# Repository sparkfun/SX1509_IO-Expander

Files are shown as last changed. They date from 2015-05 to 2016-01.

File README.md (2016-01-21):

SparkFun 16 Output I/O Expander Breakout - SX1509
======================================

[SX1509 16 Output I/O Expander Breakout  
*SX1509 16 Output I/O Expander Breakout (BOB-13601)*](https://www.sparkfun.com/products/13601)

The SX1509 16 Output I/O Expander Breakout Board makes it easy to prototype using the SX1509 so you can add more I/O onto your Arduino or I/O limited controller. It can leverage your I2C interface for 16 extra channels of GPIO and contains a fully programmable LED driver and a keypad scanning engine which enables continuous keypad monitoring of up to 64 keys. Since the I/O banks can operate between 1.2V and 3.6V (5.5V tolerant) independent of both the core and each other, this device can also work as a level-shifter.

Features include:

* 16 channels of bi-directional I/O - Pull-up/down resistors, push/pull or open-drain outputs, programmable polarity.
* 5.5V tolerant I/O's (1.2-3.6V operating voltage)
* LED Driver: PWM and blink control on all I/O's, breathe capability on a select few.
* Level shifting I/O's: Independent I/O rails (VCC1, VCC2) allow for up/down level shifting.
* Keypad scanning engine: Supports up to 64 keys (in an 8x8 matrix configuration).

Repository Contents
-------------------
* **/Hardware** - Eagle design files (.brd, .sch)
* **/Libraries** - Libraries for use with the <PRODUCT NAME>
* **/Production** - Production panel files (.brd)

Documentation
--------------
* **[Library](https://github.com/sparkfun/SparkFun_SX1509_Arduino_Library)** - <LANGUAGE> library for the SX1509.
* **[Hookup Guide](https://learn.sparkfun.com/tutorials/sx1509-io-expander-breakout-hookup-guide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)** - Basic hookup guide for the SX1509.
* **[SparkFun Fritzing repo](https://github.com/sparkfun/Fritzing_Parts)** - Fritzing diagrams for SparkFun products.
* **[SparkFun 3D Model repo](https://github.com/sparkfun/3D_Models)** - 3D models of SparkFun products. 
* **[SparkFun Graphical Datasheets](https://github.com/sparkfun/Graphical_Datasheets)** -Graphical Datasheets for various SparkFun products.

Product Versions
-------------------

* [BOB-13601](https://www.sparkfun.com/products/13601) - SX1509 16 I/O Breakout Board (v20)
* [BOB-11502](https://www.sparkfun.com/products/retired/11502)- (Retired) SX1509 16 I/O I2C port expander (v10)

License Information
-------------------
This product is _**open source**_! 

The **hardware** is released under [Creative Commons ShareAlike 4.0 International](https://creativecommons.org/licenses/by-sa/4.0/).

The **code** is beerware; if you see me (or any other SparkFun employee) at the local, and you've found our code helpful, please buy us a round!

Please use, reuse, and modify these files as you see fit. Please maintain attribution to SparkFun Electronics and release anything derivative under the same license.

Distributed as-is; no warranty is given.

- Your friends at SparkFun.

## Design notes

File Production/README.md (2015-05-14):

SparkFun <PRODUCT NAME> Production Files
=========================================

These are the production files SparkFun uses for printing PCBs.

License Information
-------------------
This product is open source! 

The hardware is released under [Creative Commons ShareAlike 4.0 International](https://creativecommons.org/licenses/by-sa/4.0/).

Please use, reuse, and modify these files as you see fit. Please maintain attribution to SparkFun Electronics and release anything derivative under the same license.

Distributed as-is; no warranty is given.

- Your friends at SparkFun.

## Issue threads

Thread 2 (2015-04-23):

SX1509 V11 Proto Checklist Issues

ericorosel, 2015-04-23:
(1) I would like to see a paste (TCream) reduction on the SX1509 outer pads (center pad looks good). As it stands, the apertures for the outer pads cover the entire pad, I think it would be beneficial to reduce these apertures by 25-50%. Ideally, I would like to see paste applied to the portion of the pads that is covered by the IC, and nothing more.

I looked at the yields for past batches, and it appears that all of the rework was due to jumpers on the SX1509 IC.

(2) I noticed some BStop objects around the IC (2) and one object around the pin_1 and pin_2 through-holes. As it stands there will be some exposed copper on the bottom.

jimblom, 2015-04-24:
1. Good call. I pulled the paste back into the edge of the pad - about a 50% reduction.
2. Phew, good catch. Deleted those.

ericorosel, 2015-04-24:
(1) The IC FP looks awesome! The TCream reduction is perfect.

(2) I'm still seeing 1 object/segment of BStop on the bottom. Copper won't be exposed, but there will be a "Hole" on the solder mask. I attached a pic.

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

jimblom, 2015-04-24:
Deleted. Thanks Eric!

Closed 2015-04-24.

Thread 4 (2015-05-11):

multiple sx1509?

sqrtmo, 2015-05-11:
Hello,
I need to connect 4 SX1509 to arduino and to use it like a keyboard. I've tried with "sx1509_keypad" example and I've created different objects for every single expander.
The init function gives me one for every single on startup, but I am getting strange behavior. Some times when I upload I have output from the buttons and some times not or I have only from one or two of them.
Can anyone help me?
Thanks in advance!

This is the code I am using:

#include <Wire.h>
#include <sx1509_library.h>

const uint8_t run_led = 13;

//Addresses
const uint8_t ADDR_1 = 0x3E;
const uint8_t ADDR_2 = 0x70;
const uint8_t ADDR_3 = 0x3F;
// Arduino pin definitions
const uint8_t nRST_1 = 16;
const uint8_t nINT_1 = 17;

const uint8_t nRST_2 = 14;
const uint8_t nINT_2 = 15;

const uint8_t nRST_3 =  2;
const uint8_t nINT_3 =  3;

const uint8_t nRows = 8;
const uint8_t nCols = 8;

sx1509Class sx1( ADDR_1, nRST_1, nINT_1 );
sx1509Class sx2( ADDR_2, nRST_2, nINT_2 );
sx1509Class sx3( ADDR_3, nRST_3, nINT_3 );

void setup()
{
    Serial.begin(9600);

    // initialize the digital pin as an output.
    pinMode(run_led, OUTPUT);
    digitalWrite(run_led, LOW); // run led off

    delay(1000); // wait for serial monitor
    sxSetup_1();
    delay(500);
    sxSetup_2();
    delay(500);
    sxSetup_3();
}

//output variables
uint8_t R1, R1Prev;
uint8_t C1, C1Prev;

uint8_t R2, R2Prev;
uint8_t C2, C2Prev;

uint8_t R3, R3Prev;
uint8_t C3, C3Prev;
//end output variables

void loop()
{
    digitalWrite(run_led, HIGH);

    sx1_Probe();
//    if( C1 != C1Prev || R1 != R1Prev )
//    {
//        Serial.print("sx1 ");
//        Serial.print(R1);
//        Serial.println(C1);
//
//    }
    delay(10);

    sx2_Probe();
//    if( C2 != C2Prev || R2 != R2Prev )
//    {
//        Serial.print("sx2 ");
//        Serial.print(R2);
//        Serial.println(C2);
//    }
    delay(10);

    sx3_Probe();
//    if( C3 != C3Prev || R3 != R3Prev )
//    {
//        Serial.print("sx3 ");
//        Serial.print(R3);
//        Serial.println(C3);
//    }
    delay(10);

    digitalWrite(run_led, LOW);

    R1Prev = R1;
    C1Prev = C1;

    R2Prev = R2;
    C2Prev = C2;

    R3Prev = R3;
    C3Prev = C3;
}
//----setup----
void sxSetup_1()
{
    int8_t x = sx1.init();

    if( x )
    {
        Serial.println("SX1 Init OK");
    } else {
        Serial.println("SX1 Init Failed");
    }

    sx1.configClock();

    byte sleepTime = 7;
    byte scanTime = 5; // Scan time per row <--<<<< 5 min for T3

    sx1.keypad(nRows, nCols, sleepTime, scanTime); // Advanced keypad init
    // We can also debounce the keypad inputs. The debounceConfig
    // method takes one parameter. Similar to the scanTime it's a
    // 3-bit value (0-7). This value must be <= scanTime!
    byte debounceTime = 1; // The debounce config value
    sx1.debounceConfig(debounceTime);
}

void sxSetup_2()
{
    int8_t x = 0;
    x = sx2.init();

    if( x )
    {
        Serial.println("SX2 Init OK");
        } else {
        Serial.println("SX2 Init Failed");
    }

    sx2.configClock();

    byte sleepTime = 7;
    byte scanTime = 5; // Scan time per row <--<<<< 5 min for T3

    sx2.keypad(nRows, nCols, sleepTime, scanTime); // Advanced keypad init
    // We can also debounce the keypad inputs. The debounceConfig
    // method takes one parameter. Similar to the scanTime it's a
    // 3-bit value (0-7). This value must be <= scanTime!
    byte debounceTime = 1; // The debounce config value
    sx2.debounceConfig(debounceTime);
}

void sxSetup_3()
{
    int8_t x = 0;
    x = sx3.init();

    if( x )
    {
        Serial.println("SX3 Init OK");
        } else {
        Serial.println("SX3 Init Failed");
    }

    sx3.configClock();

    byte sleepTime = 7;
    byte scanTime = 5; // Scan time per row <--<<<< 5 min for T3

    sx3.keypad(nRows, nCols, sleepTime, scanTime); // Advanced keypad init
    // We can also debounce the keypad inputs. The debounceConfig
    // method takes one parameter. Similar to the scanTime it's a
    // 3-bit value (0-7). This value must be <= scanTime!
    byte debounceTime = 1; // The debounce config value
    sx3.debounceConfig(debounceTime);
}
//-------------

void sx1_Probe()
{
    uint8_t out[2];

    static uint16_t keyData;
    static uint16_t previousKeyData = 0;
    static byte activeRow;
    static byte activeColumn;

    static uint16_t holdCount = 0;

    const uint8_t holdCountMax = 25;

    static uint16_t releaseCount = 0;
    static uint16_t releaseCountMax = 100;

    if (!digitalRead(nINT_1))
    {
        keyData = sx1.readKeyData();

        activeRow = keyData & 0xFF;
        activeColumn = keyData >> 8;

        activeRow = getBitPosition_1(activeRow);
        activeColumn = getBitPosition_1(activeColumn);

        if (keyData != previousKeyData)
        {
            holdCount = 0;
//            R1 = activeRow;
//            C1 = activeColumn;
                        Serial.print("sx1 ");
                        Serial.print(activeRow);
                        Serial.println(activeColumn);
        } else {
            holdCount++;
            if (holdCount > holdCountMax)
            {
//                R1 = activeRow;
//                C1 = activeColumn;
            }
        }

        releaseCount = 0;

        previousKeyData = keyData;
    }

    releaseCount++;
    if (releaseCount == releaseCountMax)
    {
        releaseCount = 0;
        previousKeyData = 0;
    }
}

void sx2_Probe()
{
    static uint16_t keyData;
    static uint16_t previousKeyData = 0;
    static uint8_t  activeRow;
    static uint8_t  activeColumn;

    static uint16_t holdCount = 0;

    const uint8_t   holdCountMax = 25;

    static uint16_t releaseCount = 0;
    static uint16_t releaseCountMax = 100;

    if ( !digitalRead(nINT_2) )
    {
        keyData = sx2.readKeyData();

        activeRow = keyData & 0xFF;
        activeColumn = keyData >> 8;

        activeRow = getBitPosition_2( activeRow );
        activeColumn = getBitPosition_2( activeColumn );

        if ( keyData != previousKeyData )
        {
            holdCount = 0;
//            R2 = activeRow;
//            C2 = activeColumn;
                        Serial.print("sx2 ");
                        Serial.print(activeRow);
                        Serial.println(activeColumn);
        } else {
    
            holdCount++; // Increment holdCount
            if ( holdCount > holdCountMax )
            {
//                R2 = activeRow;
//                C2 = activeColumn;
            }
        }
        releaseCount = 0;
        previousKeyData = keyData;
    }

    releaseCount++;

    if ( releaseCount == releaseCountMax )
    {
        releaseCount = 0;
        previousKeyData = 0;
    }
}

void sx3_Probe()
{
    static uint16_t keyData;
    static uint16_t previousKeyData = 0;
    static uint8_t  activeRow;
    static uint8_t  activeColumn;

    static uint16_t holdCount = 0;

    const uint8_t   holdCountMax = 25;

    static uint16_t releaseCount = 0;
    static uint16_t releaseCountMax = 100;

    if ( !digitalRead(nINT_3) )
    {
        keyData = sx3.readKeyData();

        activeRow = keyData & 0xFF;     //raboti kato keyData % 255
        activeColumn = keyData >> 8;    //???

        activeRow = getBitPosition_3( activeRow );
        activeColumn = getBitPosition_3( activeColumn );

        if ( keyData != previousKeyData )
        {
            holdCount = 0;
//            R3 = activeRow;
//            C3 = activeColumn;
                        Serial.print("sx3 ");
                        Serial.print(activeRow);
                        Serial.println(activeColumn);
        } else {
    
            holdCount++; // Increment holdCount
            if ( holdCount > holdCountMax )
            {
//                R3 = activeRow;
//                C3 = activeColumn;
            }
        }
        releaseCount = 0;
        previousKeyData = keyData;
    }

    releaseCount++;

    if ( releaseCount == releaseCountMax )
    {
        releaseCount = 0;
        previousKeyData = 0;
    }
}

byte getBitPosition_1( byte dataByte )
{
    for (byte i=0; i<8; i++)
    {
        if (dataByte & (1<<i))
        {
            return i;
        }
    }
    return 255; // Otherwise return an error
}

byte getBitPosition_2( byte dataByte )
{
    for (byte i=0; i<8; i++)
    {
        if (dataByte & (1<<i))
        {
            return i;
        }
    }
    return 255; // Otherwise return an error
}

byte getBitPosition_3( byte dataByte )
{
    for (byte i=0; i<8; i++)
    {
        if (dataByte & (1<<i))
        {
            return i;
        }
    }
    return 255; // Otherwise return an error
}

s22e, 2015-05-12:
Bhhh.. It works perfect when I upload with Adruino 1.0.2. With the current version 1.6.3 it makes problems!

ToniCorinne, 2015-05-19:
There was a big change in the library structure between 1.0.2 and 1.6.x on Arduino. We've updated the library, so try your code with the new library structure and see if that fixes the issue you're having.

s22e, 2015-05-24:
thanks for the replay! hmm the old lib seems to work fine with newest 1.6.4 too..

ToniCorinne, 2016-03-09:
Closing this issue out as it appears to be an issue with 1.6.3. Please reopen if you are still having issues.

Closed 2016-03-09.

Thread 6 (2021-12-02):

First call to pinMode(pin, ANALOG_OUTPUT) sets output high momentarily.

raphael-bmec-co, 2021-12-02:
The first call to `pinMode(pin, ANALOG_OUTPUT)` after `begin()` causes that pin to go high momentarily.

### Details
To avoid setting analog pins into an unknown state. We always call `analogWrite(pin, output)` before calling `pinMode(pin, ANALOG_OUTPUT)`. However, as above, on the first call to `pinMode(pin, ANALOG_OUTPUT)` the pin is momentarily set high before going to `output`.

We have worked around this by making a call `pinMode(unusedPin, ANALOG_OUTPUT)'. Obviously this would be problematic if we didn't have any unused pins.

nseidle, 2022-01-27:
Line numbers are always helpful. Did you know you can [link to them](https://github.com/sparkfun/SparkFun_SX1509_Arduino_Library/blob/master/examples/analogWrite/analogWrite.ino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)? I assume you're talking about the analogWrite example but let me know.

So what you're recommending is putting a `io.analogWrite(SX1509_LED_PIN, 0);` before [line 63](https://github.com/sparkfun/SparkFun_SX1509_Arduino_Library/blob/master/examples/analogWrite/analogWrite.ino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)?

Also note: This repo is for the hardware (PCB). The library is over [here](https://github.com/sparkfun/SparkFun_SX1509_Arduino_Library) and this issue is a library issue, not a hardware issue. It's our fault. This repo is old and dates to a time when to smashed the two together. I've removed the library from this repo to avoid future confusion.

raphael-bmec-co, 2022-01-28:
Thanks for the hint on linking to line numbers.

However, I am not talking about the analogWrite example. After initialising the chip, the first call to `pinMode(pin, ANALOG_OUTPUT)` from anywhere in any code causes said `pin` to be momentarily set high. There is some kind of bug that is causing the pin to be pulled up when the pin mode is set to analog. But this only occurs for the first call to `pinMode`. There must be some additional register configuration taking place on the first call or something? Let me know if you need further clarificaiton.

Would you like me to open this issue and move this conversation to the library repo?

nseidle, 2022-01-28:
No need to move issues, we'll try to get it finished here.

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

pinMode has an initial level setting that is default high. Try a `pinMode(pin, ANALOG_OUTPUT, LOW)` and let me know if you still have the issue.

raphael-bmec-co, 2022-01-31:
Ahhhh! Thanks @nseidle. Much appreciated.

Closed 2022-01-31.

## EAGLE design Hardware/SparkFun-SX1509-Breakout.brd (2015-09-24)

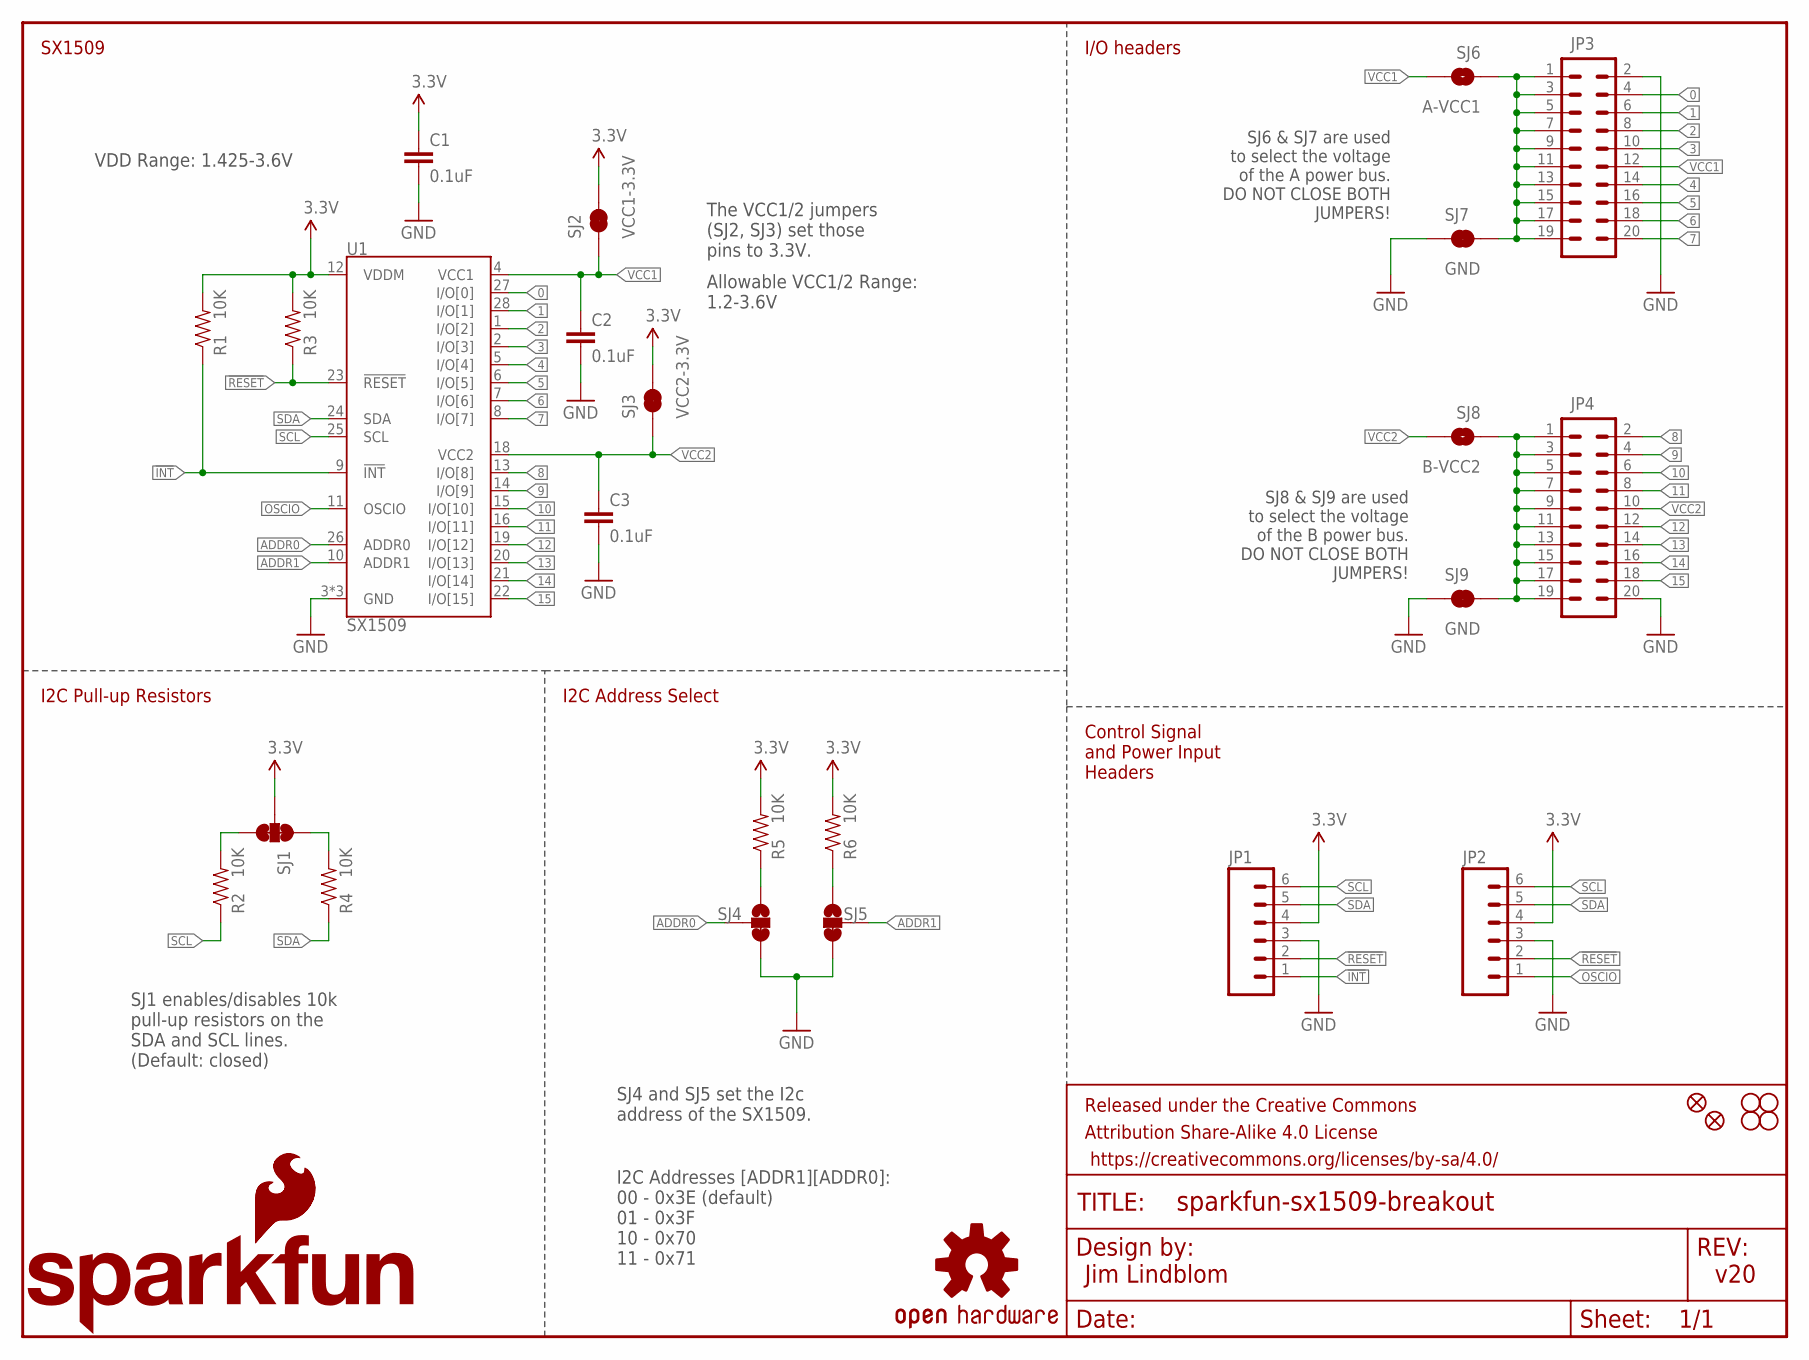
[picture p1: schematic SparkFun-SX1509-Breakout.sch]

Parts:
C1, C2, C3: 0.1uF; 0603-CAP
FRAME1: FRAME-LETTER; CREATIVE_COMMONS
JP1, JP2: M06SILK_FEMALE_PTH; 1X06
JP3, JP4: M10X2ROUND_NOSILK; 2X10_ROUND_NOSILK
JP9, JP10: FIDUCIAL1X2; FIDUCIAL-1X2
LOGO1: SFE_LOGO_NAME_FLAME.1_INCH; SFE_LOGO_NAME_FLAME_.1
LOGO2: SFE_LOGO_FLAME.1_INCH; SFE_LOGO_FLAME_.1
LOGO3: OSHW-LOGOS; OSHW-LOGO-S
R1, R2, R3, R4, R5, R6: 10K; 0603-RES
SJ1: JUMPER-PAD-3-NC_BY_TRACE; PAD-JUMPER-3-3OF3_NC_BY_TRACE_YES_SILK_FULL_BOX
SJ2: VCC1-3.3V; PAD-JUMPER-2-NC_BY_TRACE_YES_SILK
SJ3: VCC2-3.3V; PAD-JUMPER-2-NC_BY_TRACE_YES_SILK
SJ4, SJ5: JUMPER-PAD-3-2OF3_NC_BY_TRACE_SMALL; PAD-JUMPER-3-2OF3_NC_BY_TRACE_YES_SILK_FULL_BOX
SJ6: A-VCC1; PAD-JUMPER-2-NO_NO_SILK
SJ7, SJ9: GND; PAD-JUMPER-2-NC_BY_TRACE_NO_SILK
SJ8: B-VCC2; PAD-JUMPER-2-NO_NO_SILK
STANDOFF1, STANDOFF2, STANDOFF3, STANDOFF4: STAND-OFF
U1: SX1509; QFN-28

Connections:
0: JP3.4, U1.27 (I/O[0])
1: JP3.6, U1.28 (I/O[1])
2: JP3.8, U1.1 (I/O[2])
3: JP3.10, U1.2 (I/O[3])
3.3V: C1.1, JP1.4, JP2.4, R1.2, R3.2, R5.2, R6.2, SJ1.2, SJ2.2, SJ3.2, U1.12 (VDDM)
4: JP3.14, U1.5 (I/O[4])
5: JP3.16, U1.6 (I/O[5])
6: JP3.18, U1.7 (I/O[6])
7: JP3.20, U1.8 (I/O[7])
8: JP4.2, U1.13 (I/O[8])
9: JP4.4, U1.14 (I/O[9])
10: JP4.6, U1.15 (I/O[10])
11: JP4.8, U1.16 (I/O[11])
12: JP4.12, U1.19 (I/O[12])
13: JP4.14, U1.20 (I/O[13])
14: JP4.16, U1.21 (I/O[14])
15: JP4.18, U1.22 (I/O[15])
!INT: JP1.1, R1.1, U1.9 (!INT)
!RESET: JP1.2, JP2.2, R3.1, U1.23 (!RESET)
ADDR0: SJ4.2, U1.26 (ADDR0)
ADDR1: SJ5.2, U1.10 (ADDR1)
GND: C1.2, C2.2, C3.2, JP1.3, JP2.3, JP3.2, JP4.20, SJ4.3, SJ5.3, SJ7.1, SJ9.1, U1.3 (GND), U1.17 (GND), U1.29 (GND)
unnamed: R2.2, SJ1.3
unnamed: R4.2, SJ1.1
unnamed: JP4.1, JP4.3, JP4.5, JP4.7, JP4.9, JP4.11, JP4.13, JP4.15, JP4.17, JP4.19, SJ8.1, SJ9.2
unnamed: R5.1, SJ4.1
unnamed: R6.1, SJ5.1
OSCIO: JP2.1, U1.11 (OSCIO)
PWRBUSA: JP3.1, JP3.3, JP3.5, JP3.7, JP3.9, JP3.11, JP3.13, JP3.15, JP3.17, JP3.19, SJ6.1, SJ7.2
SCL: JP1.6, JP2.6, R2.1, U1.25 (SCL)
SDA: JP1.5, JP2.5, R4.1, U1.24 (SDA)
VCC1: C2.1, JP3.12, SJ2.1, SJ6.2, U1.4 (VCC1)
VCC2: C3.1, JP4.10, SJ3.1, SJ8.2, U1.18 (VCC2)

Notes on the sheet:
Jim Lindblom
The VCC1/2 jumpers (SJ2, SJ3) set those pins to 3.3V.
I2C Addresses [ADDR1][ADDR0]: 00 - 0x3E (default) 01 - 0x3F 10 - 0x70 11 - 0x71
v20
SJ1 enables/disables 10k pull-up resistors on the SDA and SCL lines. (Default: closed)
SJ4 and SJ5 set the I2c address of the SX1509.
I/O headers
Control Signal and Power Input Headers
SX1509
I2C Address Select
I2C Pull-up Resistors
VDD Range: 1.425-3.6V
Allowable VCC1/2 Range: 1.2-3.6V
SJ8 & SJ9 are used to select the voltage of the B power bus. DO NOT CLOSE BOTH JUMPERS!
SJ6 & SJ7 are used to select the voltage of the A power bus. DO NOT CLOSE BOTH JUMPERS!

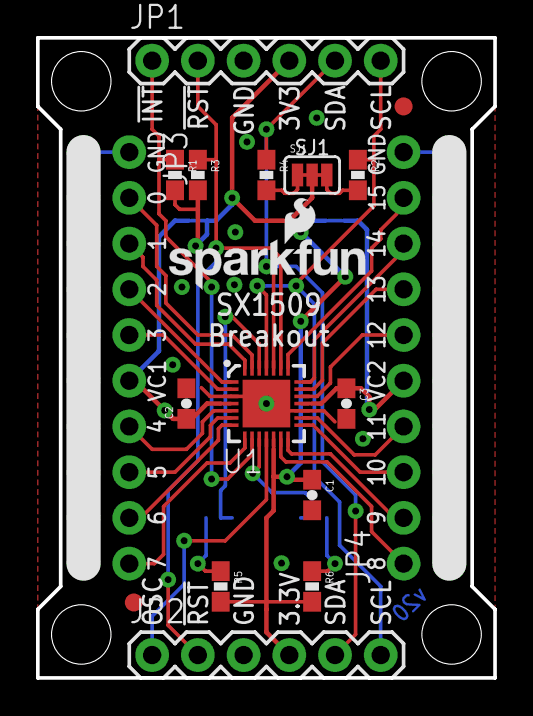
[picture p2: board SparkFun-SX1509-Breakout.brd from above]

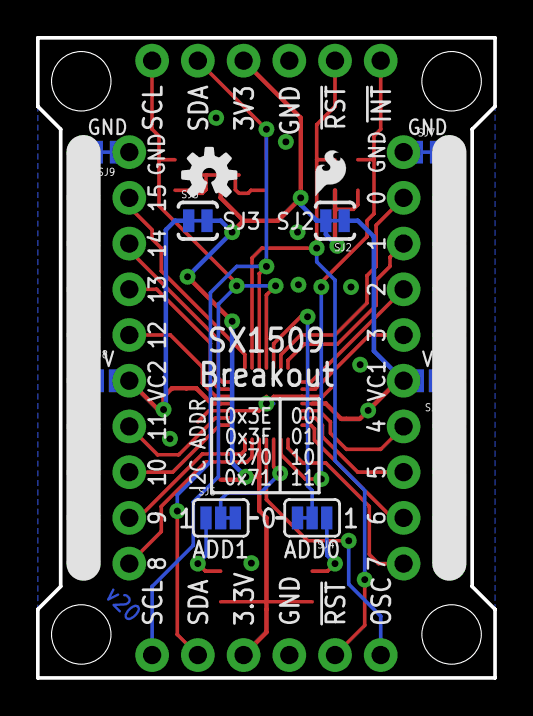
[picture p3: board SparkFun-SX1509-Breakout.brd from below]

Board: 2 copper layers, 25.4 x 35.6 mm, 33 parts (10 on the bottom side), 33 nets.

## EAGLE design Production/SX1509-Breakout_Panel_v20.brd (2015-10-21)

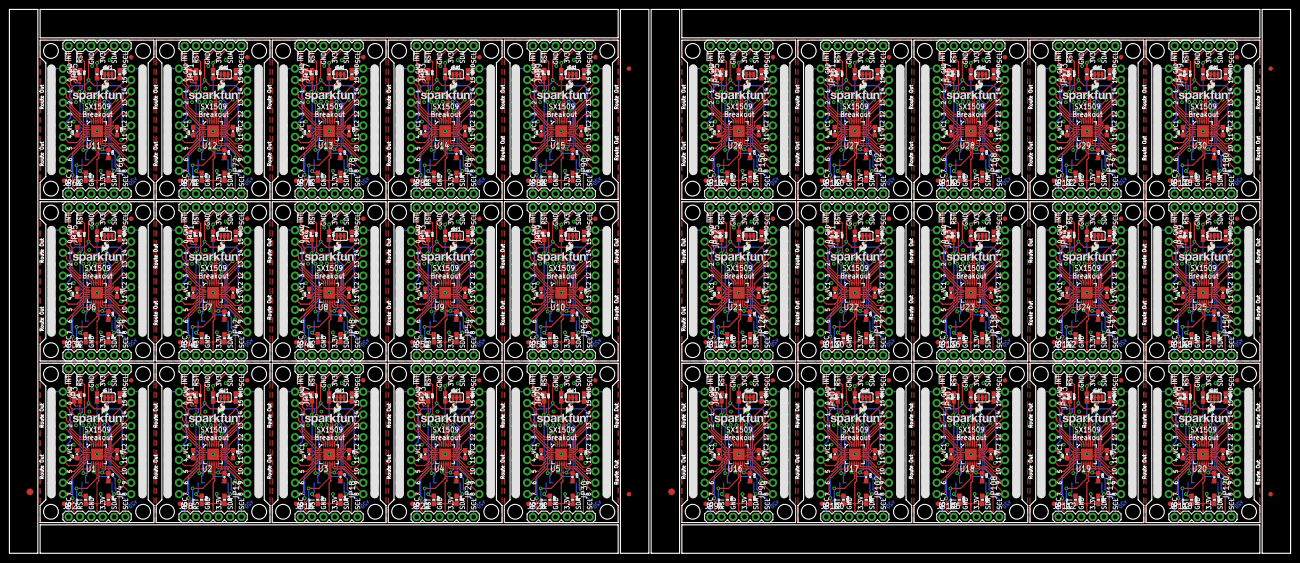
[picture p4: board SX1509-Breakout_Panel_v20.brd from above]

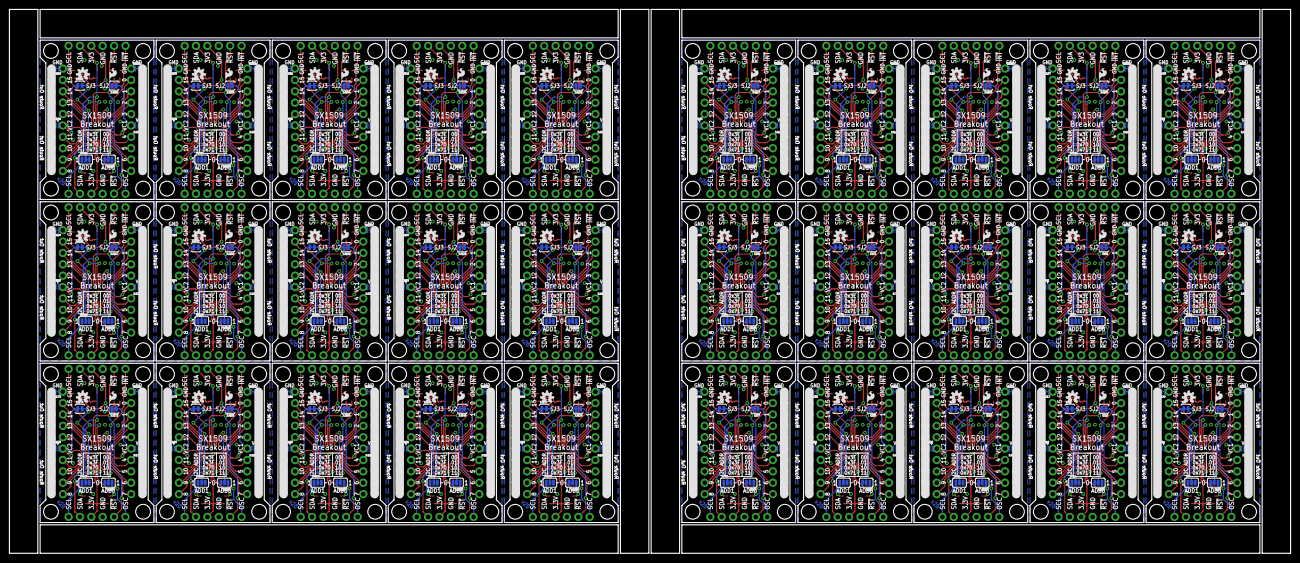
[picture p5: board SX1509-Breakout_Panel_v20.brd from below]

Board: 2 copper layers, 286.0 x 121.4 mm, 966 parts (300 on the bottom side), 990 nets.

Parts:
C1, C2, C3, C4, C5, C6, C7, C8, C9, C10, C11, C12, C13, C14, C15, C16, C17, C18, C19, C20, C21, C22, C23, C24, C25, C26, C27, C28, C29, C30, C31, C32, C33, C34, C35, C36, C37, C38, C39, C40, C41, C42, C43, C44, C45, C46, C47, C48, C49, C50, C51, C52, C53, C54, C55, C56, C57, C58, C59, C60, C61, C62, C63, C64, C65, C66, C67, C68, C69, C70, C71, C72, C73, C74, C75, C76, C77, C78, C79, C80, C81, C82, C83, C84, C85, C86, C87, C88, C89, C90: 0.1uF; 0603-CAP
E$1, E$6: FIDUCIAL-1.5X3
E$2, E$3, E$4, E$5: FIDUCIAL-1X2
JP1, JP2, JP7, JP8, JP15, JP16, JP21, JP22, JP27, JP28, JP33, JP34, JP39, JP40, JP45, JP46, JP51, JP52, JP57, JP58, JP63, JP64, JP69, JP70, JP75, JP76, JP81, JP82, JP87, JP88, JP93, JP94, JP99, JP100, JP105, JP106, JP111, JP112, JP117, JP118, JP123, JP124, JP129, JP130, JP135, JP136, JP141, JP142, JP147, JP148, JP153, JP154, JP159, JP160, JP165, JP166, JP171, JP172, JP177, JP178: 1X06
JP3, JP4, JP11, JP12, JP17, JP18, JP23, JP24, JP29, JP30, JP35, JP36, JP41, JP42, JP47, JP48, JP53, JP54, JP59, JP60, JP65, JP66, JP71, JP72, JP77, JP78, JP83, JP84, JP89, JP90, JP95, JP96, JP101, JP102, JP107, JP108, JP113, JP114, JP119, JP120, JP125, JP126, JP131, JP132, JP137, JP138, JP143, JP144, JP149, JP150, JP155, JP156, JP161, JP162, JP167, JP168, JP173, JP174, JP179, JP180: 2X10_ROUND_NOSILK
JP5, JP6, JP9, JP10, JP13, JP14, JP19, JP20, JP25, JP26, JP31, JP32, JP37, JP38, JP43, JP44, JP49, JP50, JP55, JP56, JP61, JP62, JP67, JP68, JP73, JP74, JP79, JP80, JP85, JP86, JP91, JP92, JP97, JP98, JP103, JP104, JP109, JP110, JP115, JP116, JP121, JP122, JP127, JP128, JP133, JP134, JP139, JP140, JP145, JP146, JP151, JP152, JP157, JP158, JP163, JP164, JP169, JP170, JP175, JP176: FIDUCIAL1X2; FIDUCIAL-1X2
LOGO1, LOGO6, LOGO9, LOGO12, LOGO15, LOGO18, LOGO21, LOGO24, LOGO27, LOGO30, LOGO33, LOGO36, LOGO39, LOGO42, LOGO45, LOGO48, LOGO51, LOGO54, LOGO57, LOGO60, LOGO63, LOGO66, LOGO69, LOGO72, LOGO75, LOGO78, LOGO81, LOGO84, LOGO87, LOGO90: SFE_LOGO_NAME_FLAME.1_INCH; SFE_LOGO_NAME_FLAME_.1
LOGO2, LOGO5, LOGO8, LOGO11, LOGO14, LOGO17, LOGO20, LOGO23, LOGO26, LOGO29, LOGO32, LOGO35, LOGO38, LOGO41, LOGO44, LOGO47, LOGO50, LOGO53, LOGO56, LOGO59, LOGO62, LOGO65, LOGO68, LOGO71, LOGO74, LOGO77, LOGO80, LOGO83, LOGO86, LOGO89: SFE_LOGO_FLAME.1_INCH; SFE_LOGO_FLAME_.1
LOGO3, LOGO4, LOGO7, LOGO10, LOGO13, LOGO16, LOGO19, LOGO22, LOGO25, LOGO28, LOGO31, LOGO34, LOGO37, LOGO40, LOGO43, LOGO46, LOGO49, LOGO52, LOGO55, LOGO58, LOGO61, LOGO64, LOGO67, LOGO70, LOGO73, LOGO76, LOGO79, LOGO82, LOGO85, LOGO88: OSHW-LOGOS; OSHW-LOGO-S
R1, R2, R3, R4, R5, R6, R7, R8, R9, R10, R11, R12, R13, R14, R15, R16, R17, R18, R19, R20, R21, R22, R23, R24, R25, R26, R27, R28, R29, R30, R31, R32, R33, R34, R35, R36, R37, R38, R39, R40, R41, R42, R43, R44, R45, R46, R47, R48, R49, R50, R51, R52, R53, R54, R55, R56, R57, R58, R59, R60, R61, R62, R63, R64, R65, R66, R67, R68, R69, R70, R71, R72, R73, R74, R75, R76, R77, R78, R79, R80, R81, R82, R83, R84, R85, R86, R87, R88, R89, R90, R91, R92, R93, R94, R95, R96, R97, R98, R99, R100, R101, R102, R103, R104, R105, R106, R107, R108, R109, R110, R111, R112, R113, R114, R115, R116, R117, R118, R119, R120, R121, R122, R123, R124, R125, R126, R127, R128, R129, R130, R131, R132, R133, R134, R135, R136, R137, R138, R139, R140, R141, R142, R143, R144, R145, R146, R147, R148, R149, R150, R151, R152, R153, R154, R155, R156, R157, R158, R159, R160, R161, R162, R163, R164, R165, R166, R167, R168, R169, R170, R171, R172, R173, R174, R175, R176, R177, R178, R179, R180: 10K; 0603-RES
SJ1, SJ14, SJ23, SJ32, SJ41, SJ50, SJ59, SJ68, SJ77, SJ86, SJ95, SJ104, SJ113, SJ122, SJ131, SJ140, SJ149, SJ158, SJ167, SJ176, SJ185, SJ194, SJ203, SJ212, SJ221, SJ230, SJ239, SJ248, SJ257, SJ266: PAD-JUMPER-3-3OF3_NC_BY_TRACE_YES_SILK_FULL_BOX
SJ2, SJ10, SJ19, SJ28, SJ37, SJ46, SJ55, SJ64, SJ73, SJ82, SJ91, SJ100, SJ109, SJ118, SJ127, SJ136, SJ145, SJ154, SJ163, SJ172, SJ181, SJ190, SJ199, SJ208, SJ217, SJ226, SJ235, SJ244, SJ253, SJ262: VCC1-3.3V; PAD-JUMPER-2-NC_BY_TRACE_YES_SILK
SJ3, SJ11, SJ20, SJ29, SJ38, SJ47, SJ56, SJ65, SJ74, SJ83, SJ92, SJ101, SJ110, SJ119, SJ128, SJ137, SJ146, SJ155, SJ164, SJ173, SJ182, SJ191, SJ200, SJ209, SJ218, SJ227, SJ236, SJ245, SJ254, SJ263: VCC2-3.3V; PAD-JUMPER-2-NC_BY_TRACE_YES_SILK
SJ4, SJ5, SJ12, SJ13, SJ21, SJ22, SJ30, SJ31, SJ39, SJ40, SJ48, SJ49, SJ57, SJ58, SJ66, SJ67, SJ75, SJ76, SJ84, SJ85, SJ93, SJ94, SJ102, SJ103, SJ111, SJ112, SJ120, SJ121, SJ129, SJ130, SJ138, SJ139, SJ147, SJ148, SJ156, SJ157, SJ165, SJ166, SJ174, SJ175, SJ183, SJ184, SJ192, SJ193, SJ201, SJ202, SJ210, SJ211, SJ219, SJ220, SJ228, SJ229, SJ237, SJ238, SJ246, SJ247, SJ255, SJ256, SJ264, SJ265: PAD-JUMPER-3-2OF3_NC_BY_TRACE_YES_SILK_FULL_BOX
SJ6, SJ15, SJ24, SJ33, SJ42, SJ51, SJ60, SJ69, SJ78, SJ87, SJ96, SJ105, SJ114, SJ123, SJ132, SJ141, SJ150, SJ159, SJ168, SJ177, SJ186, SJ195, SJ204, SJ213, SJ222, SJ231, SJ240, SJ249, SJ258, SJ267: A-VCC1; PAD-JUMPER-2-NO_NO_SILK
SJ7, SJ9, SJ17, SJ18, SJ26, SJ27, SJ35, SJ36, SJ44, SJ45, SJ53, SJ54, SJ62, SJ63, SJ71, SJ72, SJ80, SJ81, SJ89, SJ90, SJ98, SJ99, SJ107, SJ108, SJ116, SJ117, SJ125, SJ126, SJ134, SJ135, SJ143, SJ144, SJ152, SJ153, SJ161, SJ162, SJ170, SJ171, SJ179, SJ180, SJ188, SJ189, SJ197, SJ198, SJ206, SJ207, SJ215, SJ216, SJ224, SJ225, SJ233, SJ234, SJ242, SJ243, SJ251, SJ252, SJ260, SJ261, SJ269, SJ270: GND; PAD-JUMPER-2-NC_BY_TRACE_NO_SILK
SJ8, SJ16, SJ25, SJ34, SJ43, SJ52, SJ61, SJ70, SJ79, SJ88, SJ97, SJ106, SJ115, SJ124, SJ133, SJ142, SJ151, SJ160, SJ169, SJ178, SJ187, SJ196, SJ205, SJ214, SJ223, SJ232, SJ241, SJ250, SJ259, SJ268: B-VCC2; PAD-JUMPER-2-NO_NO_SILK
STANDOFF1, STANDOFF2, STANDOFF3, STANDOFF4, STANDOFF5, STANDOFF6, STANDOFF7, STANDOFF8, STANDOFF9, STANDOFF10, STANDOFF11, STANDOFF12, STANDOFF13, STANDOFF14, STANDOFF15, STANDOFF16, STANDOFF17, STANDOFF18, STANDOFF19, STANDOFF20, STANDOFF21, STANDOFF22, STANDOFF23, STANDOFF24, STANDOFF25, STANDOFF26, STANDOFF27, STANDOFF28, STANDOFF29, STANDOFF30, STANDOFF31, STANDOFF32, STANDOFF33, STANDOFF34, STANDOFF35, STANDOFF36, STANDOFF37, STANDOFF38, STANDOFF39, STANDOFF40, STANDOFF41, STANDOFF42, STANDOFF43, STANDOFF44, STANDOFF45, STANDOFF46, STANDOFF47, STANDOFF48, STANDOFF49, STANDOFF50, STANDOFF51, STANDOFF52, STANDOFF53, STANDOFF54, STANDOFF55, STANDOFF56, STANDOFF57, STANDOFF58, STANDOFF59, STANDOFF60, STANDOFF61, STANDOFF62, STANDOFF63, STANDOFF64, STANDOFF65, STANDOFF66, STANDOFF67, STANDOFF68, STANDOFF69, STANDOFF70, STANDOFF71, STANDOFF72, STANDOFF73, STANDOFF74, STANDOFF75, STANDOFF76, STANDOFF77, STANDOFF78, STANDOFF79, STANDOFF80, STANDOFF81, STANDOFF82, STANDOFF83, STANDOFF84, STANDOFF85, STANDOFF86, STANDOFF87, STANDOFF88, STANDOFF89, STANDOFF90, STANDOFF91, STANDOFF92, STANDOFF93, STANDOFF94, STANDOFF95, STANDOFF96, STANDOFF97, STANDOFF98, STANDOFF99, STANDOFF100, STANDOFF101, STANDOFF102, STANDOFF103, STANDOFF104, STANDOFF105, STANDOFF106, STANDOFF107, STANDOFF108, STANDOFF109, STANDOFF110, STANDOFF111, STANDOFF112, STANDOFF113, STANDOFF114, STANDOFF115, STANDOFF116, STANDOFF117, STANDOFF118, STANDOFF119, STANDOFF120: STAND-OFF
U1, U2, U3, U4, U5, U6, U7, U8, U9, U10, U11, U12, U13, U14, U15, U16, U17, U18, U19, U20, U21, U22, U23, U24, U25, U26, U27, U28, U29, U30: SX1509; QFN-28

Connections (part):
0: JP3.4, U1.27
1: JP3.6, U1.28
2: JP3.8, U1.1
3: JP3.10, U1.2
3.3V: C1.1, JP1.4, JP2.4, R1.2, R3.2, R5.2, R6.2, SJ1.2, SJ2.2, SJ3.2, U1.12
3.3V1: C4.1, JP7.4, JP8.4, R7.2, R10.2, R11.2, R12.2, SJ10.2, SJ11.2, SJ14.2, U2.12
3.3V2: C7.1, JP15.4, JP16.4, R13.2, R16.2, R17.2, R18.2, SJ19.2, SJ20.2, SJ23.2, U3.12
3.3V3: C10.1, JP21.4, JP22.4, R19.2, R22.2, R23.2, R24.2, SJ28.2, SJ29.2, SJ32.2, U4.12
3.3V4: C13.1, JP27.4, JP28.4, R25.2, R28.2, R29.2, R30.2, SJ37.2, SJ38.2, SJ41.2, U5.12
3.3V5: C16.1, JP33.4, JP34.4, R31.2, R34.2, R35.2, R36.2, SJ46.2, SJ47.2, SJ50.2, U6.12
3.3V6: C19.1, JP39.4, JP40.4, R37.2, R40.2, R41.2, R42.2, SJ55.2, SJ56.2, SJ59.2, U7.12
3.3V7: C22.1, JP45.4, JP46.4, R43.2, R46.2, R47.2, R48.2, SJ64.2, SJ65.2, SJ68.2, U8.12
3.3V8: C25.1, JP51.4, JP52.4, R49.2, R52.2, R53.2, R54.2, SJ73.2, SJ74.2, SJ77.2, U9.12
3.3V9: C28.1, JP57.4, JP58.4, R55.2, R58.2, R59.2, R60.2, SJ82.2, SJ83.2, SJ86.2, U10.12
3.3V10: C31.1, JP63.4, JP64.4, R61.2, R64.2, R65.2, R66.2, SJ91.2, SJ92.2, SJ95.2, U11.12
3.3V11: C34.1, JP69.4, JP70.4, R67.2, R70.2, R71.2, R72.2, SJ100.2, SJ101.2, SJ104.2, U12.12
3.3V12: C37.1, JP75.4, JP76.4, R73.2, R76.2, R77.2, R78.2, SJ109.2, SJ110.2, SJ113.2, U13.12
3.3V13: C40.1, JP81.4, JP82.4, R79.2, R82.2, R83.2, R84.2, SJ118.2, SJ119.2, SJ122.2, U14.12
3.3V14: C43.1, JP87.4, JP88.4, R85.2, R88.2, R89.2, R90.2, SJ127.2, SJ128.2, SJ131.2, U15.12
3.3V15: C46.1, JP93.4, JP94.4, R91.2, R94.2, R95.2, R96.2, SJ136.2, SJ137.2, SJ140.2, U16.12
3.3V16: C49.1, JP99.4, JP100.4, R97.2, R100.2, R101.2, R102.2, SJ145.2, SJ146.2, SJ149.2, U17.12
3.3V17: C52.1, JP105.4, JP106.4, R103.2, R106.2, R107.2, R108.2, SJ154.2, SJ155.2, SJ158.2, U18.12
3.3V18: C55.1, JP111.4, JP112.4, R109.2, R112.2, R113.2, R114.2, SJ163.2, SJ164.2, SJ167.2, U19.12
3.3V19: C58.1, JP117.4, JP118.4, R115.2, R118.2, R119.2, R120.2, SJ172.2, SJ173.2, SJ176.2, U20.12
3.3V20: C61.1, JP123.4, JP124.4, R121.2, R124.2, R125.2, R126.2, SJ181.2, SJ182.2, SJ185.2, U21.12
3.3V21: C64.1, JP129.4, JP130.4, R127.2, R130.2, R131.2, R132.2, SJ190.2, SJ191.2, SJ194.2, U22.12
3.3V22: C67.1, JP135.4, JP136.4, R133.2, R136.2, R137.2, R138.2, SJ199.2, SJ200.2, SJ203.2, U23.12
3.3V23: C70.1, JP141.4, JP142.4, R139.2, R142.2, R143.2, R144.2, SJ208.2, SJ209.2, SJ212.2, U24.12
3.3V24: C73.1, JP147.4, JP148.4, R145.2, R148.2, R149.2, R150.2, SJ217.2, SJ218.2, SJ221.2, U25.12
3.3V25: C76.1, JP153.4, JP154.4, R151.2, R154.2, R155.2, R156.2, SJ226.2, SJ227.2, SJ230.2, U26.12
3.3V26: C79.1, JP159.4, JP160.4, R157.2, R160.2, R161.2, R162.2, SJ235.2, SJ236.2, SJ239.2, U27.12
3.3V27: C82.1, JP165.4, JP166.4, R163.2, R166.2, R167.2, R168.2, SJ244.2, SJ245.2, SJ248.2, U28.12
3.3V28: C85.1, JP171.4, JP172.4, R169.2, R172.2, R173.2, R174.2, SJ253.2, SJ254.2, SJ257.2, U29.12
3.3V29: C88.1, JP177.4, JP178.4, R175.2, R178.2, R179.2, R180.2, SJ262.2, SJ263.2, SJ266.2, U30.12
4: JP3.14, U1.5
5: JP3.16, U1.6
6: JP3.18, U1.7
7: JP3.20, U1.8
8: JP4.2, U1.13
9: JP4.4, U1.14
10: JP4.6, U1.15
11: JP4.8, U1.16
12: JP4.12, U1.19
13: JP4.14, U1.20
14: JP4.16, U1.21
15: JP4.18, U1.22
16: JP12.2, U2.13
17: JP12.4, U2.14
18: JP12.6, U2.15
19: JP12.8, U2.16
20: JP12.12, U2.19
21: JP12.14, U2.20
22: JP12.16, U2.21
23: JP12.18, U2.22
24: JP11.4, U2.27
25: JP11.6, U2.28
26: JP11.8, U2.1
27: JP11.10, U2.2
28: JP11.14, U2.5
29: JP11.16, U2.6
30: JP11.18, U2.7
31: JP11.20, U2.8
32: JP18.2, U3.13
33: JP18.4, U3.14
34: JP18.6, U3.15
35: JP18.8, U3.16
36: JP18.12, U3.19
37: JP18.14, U3.20
38: JP18.16, U3.21
39: JP18.18, U3.22
40: JP17.4, U3.27
41: JP17.6, U3.28
42: JP17.8, U3.1
43: JP17.10, U3.2
44: JP17.14, U3.5
45: JP17.16, U3.6
46: JP17.18, U3.7
47: JP17.20, U3.8
48: JP24.2, U4.13
49: JP24.4, U4.14
50: JP24.6, U4.15
51: JP24.8, U4.16
52: JP24.12, U4.19
53: JP24.14, U4.20
54: JP24.16, U4.21
55: JP24.18, U4.22
56: JP23.4, U4.27
57: JP23.6, U4.28
58: JP23.8, U4.1
59: JP23.10, U4.2
60: JP23.14, U4.5
61: JP23.16, U4.6
62: JP23.18, U4.7
63: JP23.20, U4.8
64: JP30.2, U5.13
65: JP30.4, U5.14
66: JP30.6, U5.15
67: JP30.8, U5.16
68: JP30.12, U5.19
69: JP30.14, U5.20
70: JP30.16, U5.21
71: JP30.18, U5.22
72: JP29.4, U5.27
73: JP29.6, U5.28
74: JP29.8, U5.1
75: JP29.10, U5.2
76: JP29.14, U5.5
77: JP29.16, U5.6
78: JP29.18, U5.7
79: JP29.20, U5.8
80: JP36.2, U6.13
81: JP36.4, U6.14
82: JP36.6, U6.15
83: JP36.8, U6.16
84: JP36.12, U6.19
85: JP36.14, U6.20
86: JP36.16, U6.21
87: JP36.18, U6.22
88: JP35.4, U6.27
89: JP35.6, U6.28
90: JP35.8, U6.1
91: JP35.10, U6.2
92: JP35.14, U6.5
93: JP35.16, U6.6
94: JP35.18, U6.7
95: JP35.20, U6.8
96: JP42.2, U7.13
97: JP42.4, U7.14
98: JP42.6, U7.15
99: JP42.8, U7.16
100: JP42.12, U7.19
101: JP42.14, U7.20
102: JP42.16, U7.21
103: JP42.18, U7.22
104: JP41.4, U7.27
105: JP41.6, U7.28
106: JP41.8, U7.1
107: JP41.10, U7.2
108: JP41.14, U7.5
109: JP41.16, U7.6
110: JP41.18, U7.7
111: JP41.20, U7.8
112: JP48.2, U8.13
113: JP48.4, U8.14
114: JP48.6, U8.15
115: JP48.8, U8.16
116: JP48.12, U8.19
117: JP48.14, U8.20
118: JP48.16, U8.21
119: JP48.18, U8.22
120: JP47.4, U8.27
121: JP47.6, U8.28
122: JP47.8, U8.1
123: JP47.10, U8.2
124: JP47.14, U8.5
125: JP47.16, U8.6
126: JP47.18, U8.7
127: JP47.20, U8.8
128: JP54.2, U9.13
129: JP54.4, U9.14
130: JP54.6, U9.15
131: JP54.8, U9.16
132: JP54.12, U9.19
133: JP54.14, U9.20
134: JP54.16, U9.21
135: JP54.18, U9.22
136: JP53.4, U9.27
137: JP53.6, U9.28
138: JP53.8, U9.1
139: JP53.10, U9.2
140: JP53.14, U9.5
141: JP53.16, U9.6
142: JP53.18, U9.7
143: JP53.20, U9.8
144: JP60.2, U10.13
145: JP60.4, U10.14
146: JP60.6, U10.15
147: JP60.8, U10.16
148: JP60.12, U10.19
149: JP60.14, U10.20
150: JP60.16, U10.21
151: JP60.18, U10.22
152: JP59.4, U10.27
153: JP59.6, U10.28
154: JP59.8, U10.1
155: JP59.10, U10.2
156: JP59.14, U10.5
157: JP59.16, U10.6
158: JP59.18, U10.7
159: JP59.20, U10.8
160: JP66.2, U11.13
161: JP66.4, U11.14
162: JP66.6, U11.15
163: JP66.8, U11.16
164: JP66.12, U11.19
165: JP66.14, U11.20
166: JP66.16, U11.21
167: JP66.18, U11.22
168: JP65.4, U11.27
169: JP65.6, U11.28
170: JP65.8, U11.1
171: JP65.10, U11.2
172: JP65.14, U11.5
173: JP65.16, U11.6
174: JP65.18, U11.7
175: JP65.20, U11.8
176: JP72.2, U12.13
177: JP72.4, U12.14
178: JP72.6, U12.15
179: JP72.8, U12.16
180: JP72.12, U12.19
181: JP72.14, U12.20
182: JP72.16, U12.21
183: JP72.18, U12.22
184: JP71.4, U12.27
185: JP71.6, U12.28
186: JP71.8, U12.1
187: JP71.10, U12.2
188: JP71.14, U12.5
189: JP71.16, U12.6
190: JP71.18, U12.7
191: JP71.20, U12.8
192: JP78.2, U13.13
193: JP78.4, U13.14
194: JP78.6, U13.15
195: JP78.8, U13.16
196: JP78.12, U13.19
197: JP78.14, U13.20
198: JP78.16, U13.21
199: JP78.18, U13.22
200: JP77.4, U13.27
201: JP77.6, U13.28
202: JP77.8, U13.1
203: JP77.10, U13.2
204: JP77.14, U13.5
205: JP77.16, U13.6
206: JP77.18, U13.7
207: JP77.20, U13.8
208: JP84.2, U14.13
209: JP84.4, U14.14
210: JP84.6, U14.15
211: JP84.8, U14.16
212: JP84.12, U14.19
213: JP84.14, U14.20
214: JP84.16, U14.21
215: JP84.18, U14.22
216: JP83.4, U14.27
217: JP83.6, U14.28
218: JP83.8, U14.1
219: JP83.10, U14.2
220: JP83.14, U14.5
221: JP83.16, U14.6
222: JP83.18, U14.7
223: JP83.20, U14.8
224: JP90.2, U15.13
225: JP90.4, U15.14
226: JP90.6, U15.15
227: JP90.8, U15.16
228: JP90.12, U15.19
229: JP90.14, U15.20
230: JP90.16, U15.21
231: JP90.18, U15.22
232: JP89.4, U15.27
233: JP89.6, U15.28
234: JP89.8, U15.1
235: JP89.10, U15.2
236: JP89.14, U15.5
237: JP89.16, U15.6
238: JP89.18, U15.7
239: JP89.20, U15.8
240: JP96.2, U16.13
241: JP96.4, U16.14
242: JP96.6, U16.15
243: JP96.8, U16.16
244: JP96.12, U16.19
245: JP96.14, U16.20
246: JP96.16, U16.21
247: JP96.18, U16.22
248: JP95.4, U16.27
249: JP95.6, U16.28
250: JP95.8, U16.1
251: JP95.10, U16.2
252: JP95.14, U16.5
253: JP95.16, U16.6
254: JP95.18, U16.7
255: JP95.20, U16.8
256: JP102.2, U17.13
257: JP102.4, U17.14
258: JP102.6, U17.15
259: JP102.8, U17.16
260: JP102.12, U17.19
261: JP102.14, U17.20
262: JP102.16, U17.21
263: JP102.18, U17.22
264: JP101.4, U17.27
265: JP101.6, U17.28
266: JP101.8, U17.1
267: JP101.10, U17.2
268: JP101.14, U17.5
269: JP101.16, U17.6
270: JP101.18, U17.7
271: JP101.20, U17.8
272: JP108.2, U18.13
273: JP108.4, U18.14
274: JP108.6, U18.15
275: JP108.8, U18.16
276: JP108.12, U18.19
277: JP108.14, U18.20
278: JP108.16, U18.21
279: JP108.18, U18.22
280: JP107.4, U18.27
281: JP107.6, U18.28
282: JP107.8, U18.1
283: JP107.10, U18.2
284: JP107.14, U18.5
285: JP107.16, U18.6
286: JP107.18, U18.7
287: JP107.20, U18.8
288: JP114.2, U19.13
289: JP114.4, U19.14
290: JP114.6, U19.15
291: JP114.8, U19.16
292: JP114.12, U19.19
293: JP114.14, U19.20
294: JP114.16, U19.21
295: JP114.18, U19.22
296: JP113.4, U19.27
297: JP113.6, U19.28
298: JP113.8, U19.1
299: JP113.10, U19.2
300: JP113.14, U19.5
301: JP113.16, U19.6
302: JP113.18, U19.7
303: JP113.20, U19.8
304: JP120.2, U20.13
305: JP120.4, U20.14
306: JP120.6, U20.15
307: JP120.8, U20.16
308: JP120.12, U20.19
309: JP120.14, U20.20
310: JP120.16, U20.21
311: JP120.18, U20.22
312: JP119.4, U20.27
313: JP119.6, U20.28
314: JP119.8, U20.1
315: JP119.10, U20.2
316: JP119.14, U20.5
317: JP119.16, U20.6
318: JP119.18, U20.7
319: JP119.20, U20.8
320: JP126.2, U21.13
321: JP126.4, U21.14
322: JP126.6, U21.15
323: JP126.8, U21.16
324: JP126.12, U21.19
325: JP126.14, U21.20
326: JP126.16, U21.21
327: JP126.18, U21.22
328: JP125.4, U21.27
329: JP125.6, U21.28
330: JP125.8, U21.1
331: JP125.10, U21.2
332: JP125.14, U21.5
333: JP125.16, U21.6
334: JP125.18, U21.7
335: JP125.20, U21.8
336: JP132.2, U22.13
337: JP132.4, U22.14
338: JP132.6, U22.15
339: JP132.8, U22.16
340: JP132.12, U22.19
341: JP132.14, U22.20
342: JP132.16, U22.21
343: JP132.18, U22.22
344: JP131.4, U22.27
345: JP131.6, U22.28
346: JP131.8, U22.1
347: JP131.10, U22.2
348: JP131.14, U22.5
349: JP131.16, U22.6
350: JP131.18, U22.7
351: JP131.20, U22.8
352: JP138.2, U23.13
353: JP138.4, U23.14
354: JP138.6, U23.15
355: JP138.8, U23.16
356: JP138.12, U23.19
357: JP138.14, U23.20
358: JP138.16, U23.21
359: JP138.18, U23.22
360: JP137.4, U23.27
361: JP137.6, U23.28
362: JP137.8, U23.1
363: JP137.10, U23.2
364: JP137.14, U23.5
365: JP137.16, U23.6
366: JP137.18, U23.7
367: JP137.20, U23.8
368: JP144.2, U24.13
369: JP144.4, U24.14
370: JP144.6, U24.15
371: JP144.8, U24.16
372: JP144.12, U24.19
373: JP144.14, U24.20
374: JP144.16, U24.21
375: JP144.18, U24.22
376: JP143.4, U24.27
377: JP143.6, U24.28
378: JP143.8, U24.1
379: JP143.10, U24.2
380: JP143.14, U24.5
381: JP143.16, U24.6
382: JP143.18, U24.7
383: JP143.20, U24.8
384: JP150.2, U25.13
385: JP150.4, U25.14
386: JP150.6, U25.15
387: JP150.8, U25.16
388: JP150.12, U25.19
389: JP150.14, U25.20
390: JP150.16, U25.21
391: JP150.18, U25.22
392: JP149.4, U25.27
393: JP149.6, U25.28
394: JP149.8, U25.1
395: JP149.10, U25.2
396: JP149.14, U25.5
397: JP149.16, U25.6
398: JP149.18, U25.7
399: JP149.20, U25.8
400: JP156.2, U26.13
401: JP156.4, U26.14
402: JP156.6, U26.15
403: JP156.8, U26.16
404: JP156.12, U26.19
405: JP156.14, U26.20
406: JP156.16, U26.21
407: JP156.18, U26.22
408: JP155.4, U26.27
409: JP155.6, U26.28
410: JP155.8, U26.1
411: JP155.10, U26.2
412: JP155.14, U26.5
413: JP155.16, U26.6
414: JP155.18, U26.7
415: JP155.20, U26.8
416: JP162.2, U27.13
417: JP162.4, U27.14
418: JP162.6, U27.15
419: JP162.8, U27.16
420: JP162.12, U27.19
421: JP162.14, U27.20
422: JP162.16, U27.21
423: JP162.18, U27.22
424: JP161.4, U27.27
425: JP161.6, U27.28
426: JP161.8, U27.1
427: JP161.10, U27.2
428: JP161.14, U27.5
429: JP161.16, U27.6
430: JP161.18, U27.7
431: JP161.20, U27.8
432: JP168.2, U28.13
433: JP168.4, U28.14
434: JP168.6, U28.15
435: JP168.8, U28.16
436: JP168.12, U28.19
437: JP168.14, U28.20
438: JP168.16, U28.21
439: JP168.18, U28.22
440: JP167.4, U28.27
441: JP167.6, U28.28
442: JP167.8, U28.1
443: JP167.10, U28.2
444: JP167.14, U28.5
445: JP167.16, U28.6
446: JP167.18, U28.7
447: JP167.20, U28.8
448: JP174.2, U29.13
449: JP174.4, U29.14
450: JP174.6, U29.15
451: JP174.8, U29.16
452: JP174.12, U29.19
453: JP174.14, U29.20
454: JP174.16, U29.21
455: JP174.18, U29.22
456: JP173.4, U29.27
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

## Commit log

2015-04-17 Initial commit of v1.1
    - Added standoff holes
    - Changed I2C headers to match SparkFun standard
    - Added I2C pins to both sides to allow cascading boards.
    - Updated Eagle libraries
    - Updated 0402 packages to 0603.
    - Increase fiducial size
    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
    [sx1509-breakout.brd, sx1509-breakout.sch]
2015-04-17 Labeling SJ4 and SJ5.
    [sx1509-breakout.brd, sx1509-breakout.sch]
2015-04-20 Adding silk around headers. Labeling SJ1.
    [sx1509-breakout.brd, sx1509-breakout.sch]
2015-04-21 Revising GPIO headers to single 2x10 header.
    [sx1509-breakout.brd, sx1509-breakout.sch]
2015-04-24 Reducing paste aperature on SX1509 pads. Removing extra bStops.
    [sx1509-breakout.brd, sx1509-breakout.sch]
2015-04-24 Getting rid of one last bStop strip.
    [sx1509-breakout.brd]
2015-04-24 Temporarily removing Arduino library (will subtree).
2015-04-24 Squashed 'Libraries/Arduino/' content from commit 08ad7b0
    git-subtree-dir: Libraries/Arduino
    git-subtree-split: 08ad7b0ec1d5bc0ac4824297f483f439bb08fdc4
2015-05-14 Updating readmes
    [SparkFun_SX1509_Breakout.brd, SparkFun_SX1509_Breakout.sch]
2015-05-29 Making power busses selectable. Moving silk.
    - Not defaulting the two power bus headers to either GND or VCC.
    - Adding two jumpers on each header to allow connecting them high or low.
    - This will make it easier to set up LEDs as either source or sink.
    - It'll also make it easier to short VCC to GND - will require extra
    caution using the jumpers.
    [sx1509-breakout.brd, sx1509-breakout.sch]
2015-06-01 Defaulting power busses to GND. Moving SJ2&3.
    [sx1509-breakout.brd, sx1509-breakout.sch]
2015-06-05 created panel v20
    [SX1509-Breakout_Panel_v20.brd]
2015-09-23 Updating readme. Standardizing Production files directory name
    [SX1509-Breakout_Panel_v20.brd]
2015-09-23 Squashed 'Libraries/Arduino/' content from commit 87ced48
    git-subtree-split: 87ced48f5688efb6576cbd1612476fe53a08c703
    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
2015-09-23 Adding Arduino library as a subtree.
2015-09-23 Fixing hardware folder name
    [sx1509-breakout.brd, sx1509-breakout.sch]
2015-09-23 Removing readme for old board
2015-09-24 Standardizing Eagle file names
    [SparkFun-SX1509-Breakout.brd, SparkFun-SX1509-Breakout.sch]
2015-10-21 made panel v20 larger
    [SX1509-Breakout_Panel_v20.brd]
2022-01-27 Removing old library from repo. Point at current Arduino library repo.

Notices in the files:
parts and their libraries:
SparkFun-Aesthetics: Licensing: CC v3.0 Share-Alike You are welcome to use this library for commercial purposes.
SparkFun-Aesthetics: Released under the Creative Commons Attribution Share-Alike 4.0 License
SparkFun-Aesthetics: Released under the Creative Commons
